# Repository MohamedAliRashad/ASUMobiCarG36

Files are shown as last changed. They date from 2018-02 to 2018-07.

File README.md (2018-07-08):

# ASUMobiCarG36
ASU project for a smart car

**Phase 1** video for the car click [Here](https://youtu.be/Kc8boilaBuo)

## Components

1- 2x motors like this [Here](https://store.fut-electronics.com/products/dc-geared-motor-with-metal-gear-8-8kg-250rpm-12v-1) ........................... [Done]

2- Ball Caster like [this](https://www.robotshop.com/en/pololu-ball-caster-3-8-in-metal-ball.html) ........................... [Done]

3- Bluetooth Module from [Here](https://store.fut-electronics.com/products/serial-bluetooth-module-master-slave) ........................... [Done]

4- Atmega chip (atmega328p was suggested) from [Here](https://store.fut-electronics.com/products/atmega328-microcontroller-with-bootloader-for-uno) ........................... [Done]

5- line follower sensor ........................... [Done]

## Assembling

**The Finished Car will look like this**
we have made a whole new Design for the Line Follower Competition and it looked like this.
The designs and edits are in the Designing Folder

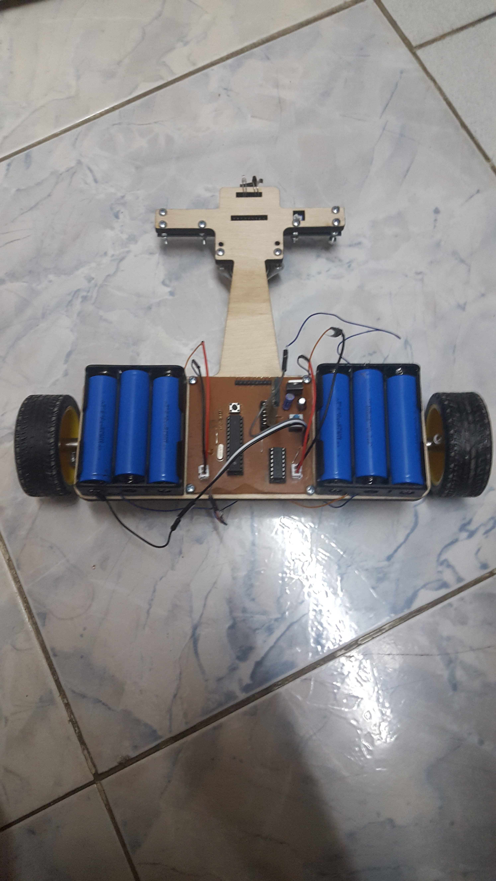
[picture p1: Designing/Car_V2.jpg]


## Programming
we have managed to program the car not only to be controlled by Bluetooth but with obstacle avoidance using IR sensor

## Line Following (Phase 2)
The Car Finished the proposed track as intended but with low speed which we are trying to improve right now.

**Phase 2** video for the Car **line following Mode** Click [Here](https://www.youtube.com/watch?v=1ZHcCvf_tag&feature=youtu.be)

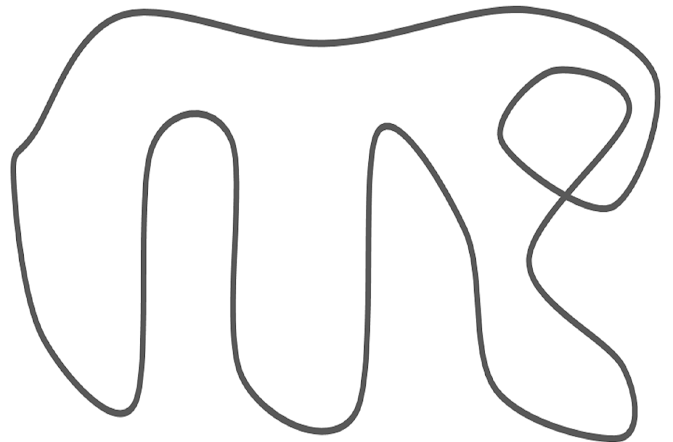
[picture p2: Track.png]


## Accurate Movement (Phase 3)

We managed to redesign the car for Accurate Movement and not to lose any important features we previously had.

**Phase 3** video for the car Click [Here](https://youtu.be/vXAHt9X1ldg)
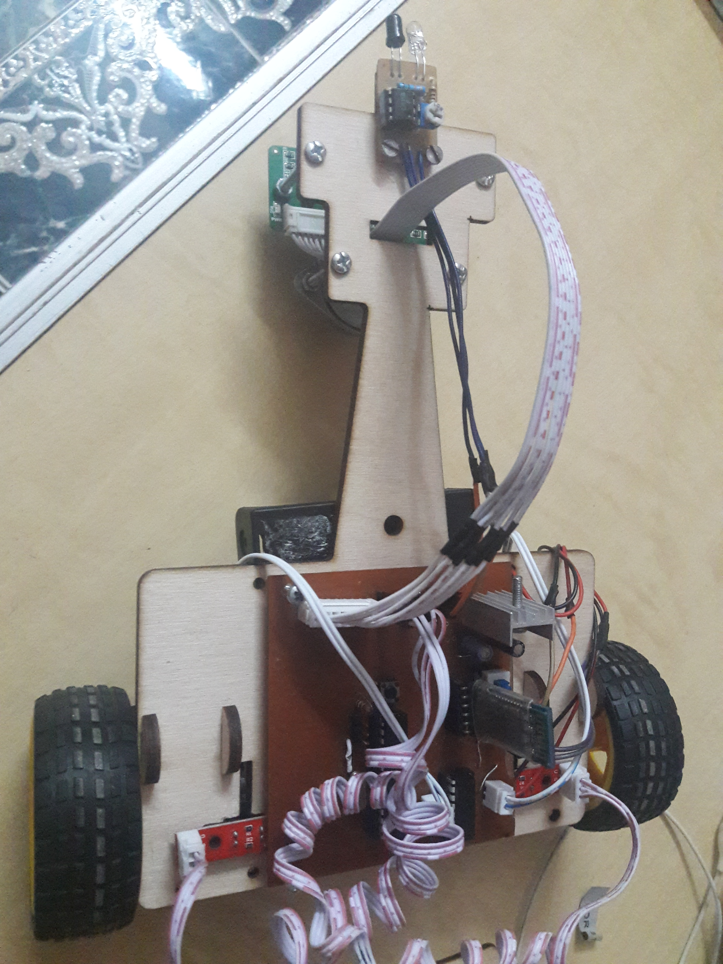
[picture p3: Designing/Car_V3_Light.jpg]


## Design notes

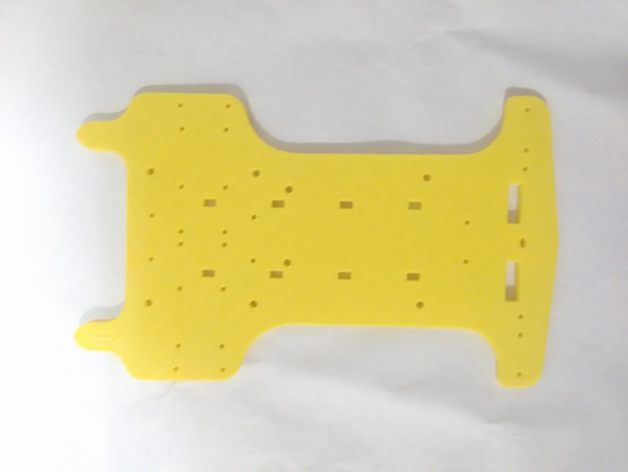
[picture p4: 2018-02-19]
Designing/Usain/images/0fe4a5ff5cf32486fa10856eb8f82ae0_preview_featured.jpg

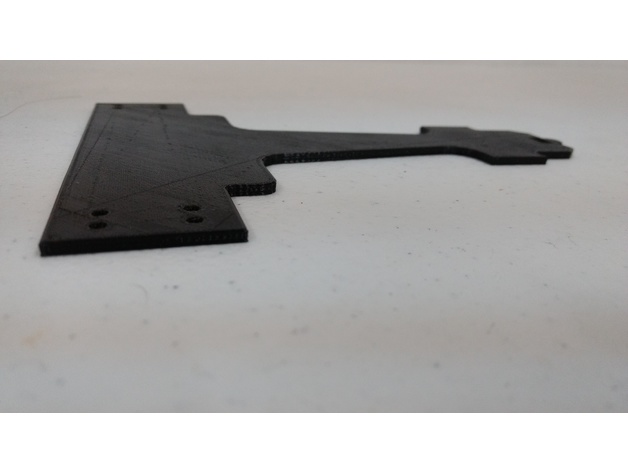
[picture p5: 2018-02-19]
Designing/Target/images/a4c6c6e0c1ed7add883d5088abed4bb4_preview_featured.jpg

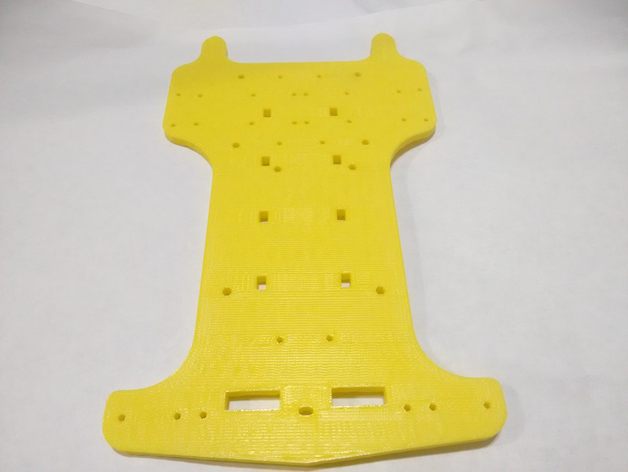
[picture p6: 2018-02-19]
Designing/Usain/images/7745294e8512e141715a2a82b8f7527b_preview_featured.jpg

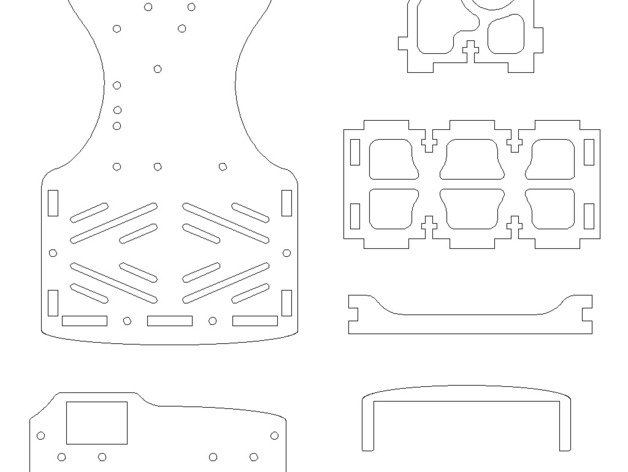
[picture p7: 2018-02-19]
Designing/Chariot/images/609b507f4311383388c29d5d0938cc0f_preview_featured.jpg

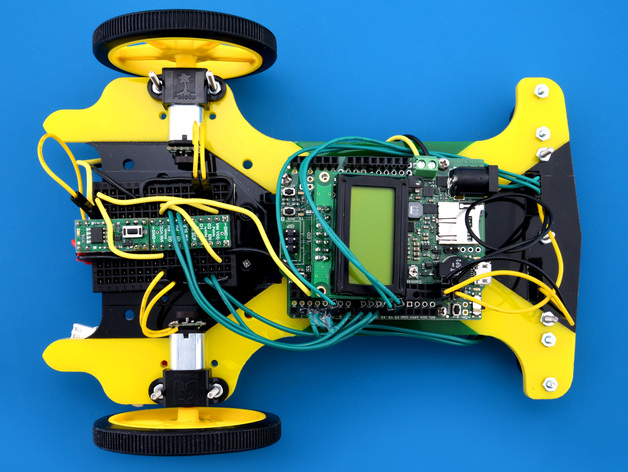
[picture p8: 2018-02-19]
Designing/Usain/images/top_preview_featured.jpg

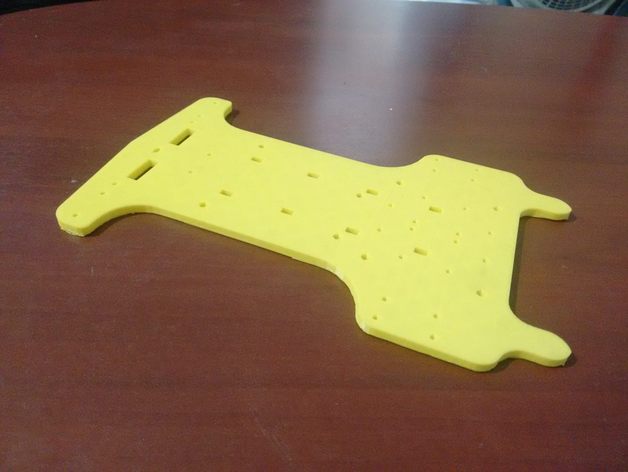
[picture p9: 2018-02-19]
Designing/Usain/images/d5540c52f5ededbf4ffe35892c21d28c_preview_featured.jpg

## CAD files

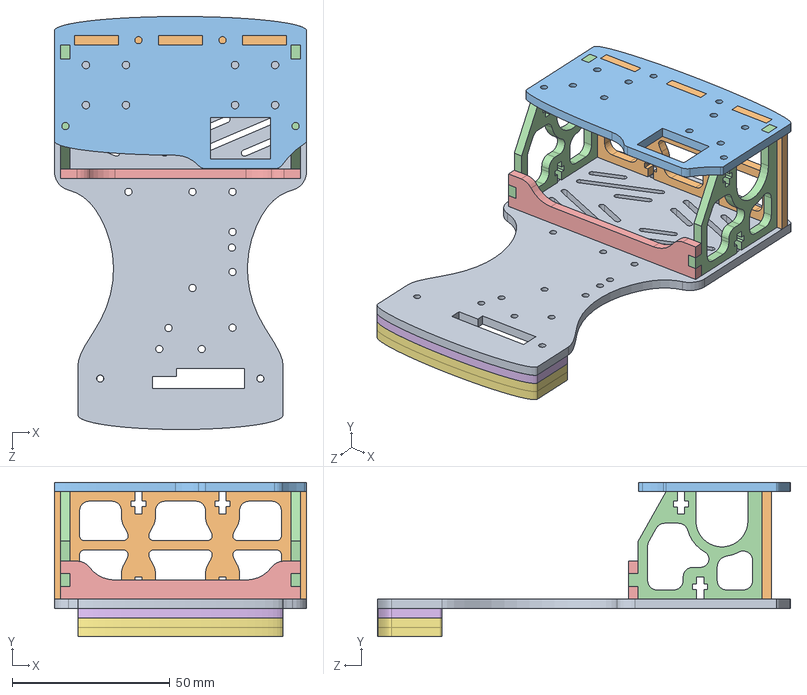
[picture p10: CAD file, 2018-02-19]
Designing/Chariot/files/bare-chassis.SLDASM
80.0 x 49.0 x 131.0 mm
chariot-base
chariot-back-wall
chariot-top
chariot-side-walls x 2
chariot-front-wall
chariot-led-shroud
chariot-led-shroud2 x 2

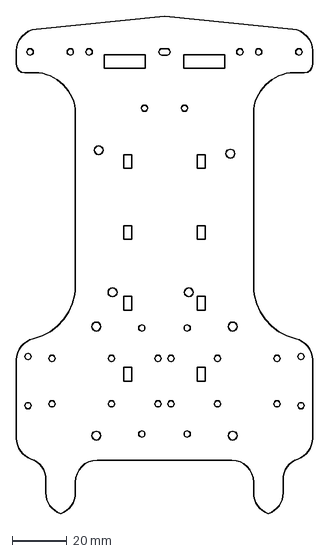
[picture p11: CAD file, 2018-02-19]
Designing/Usain/files/usain_volt_clear_full_body_piece.DXF
108.5 x 182.2 mm

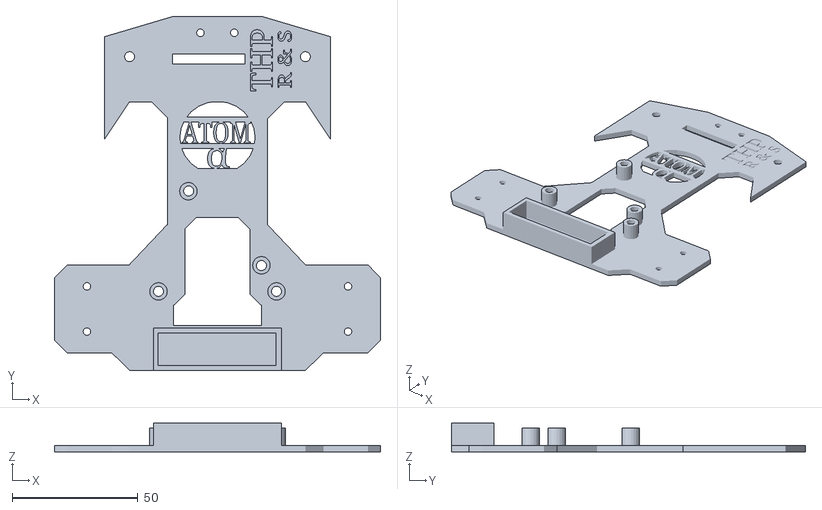
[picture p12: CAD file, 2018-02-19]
Designing/Atom/files/Atom_Alpha.stl
130.0 x 141.0 x 11.5

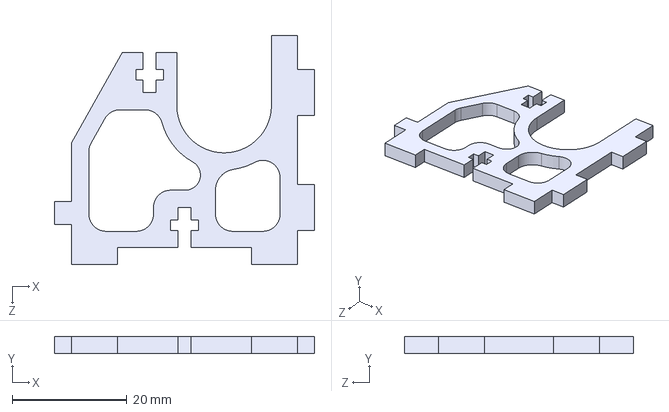
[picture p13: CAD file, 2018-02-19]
Designing/Chariot/files/chariot-side-walls.STEP
45.3 x 3.00 x 40.0 mm

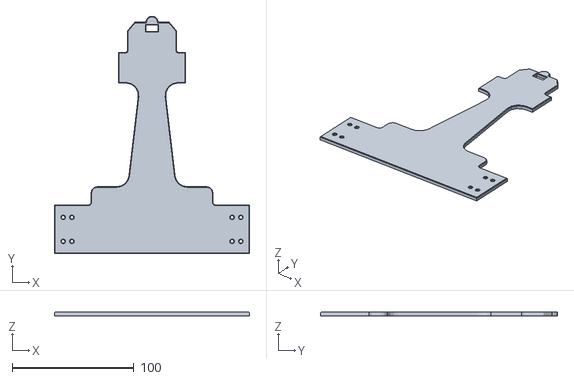
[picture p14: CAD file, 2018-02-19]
Designing/Target/files/chasis.stl
160.0 x 194.8 x 3.00

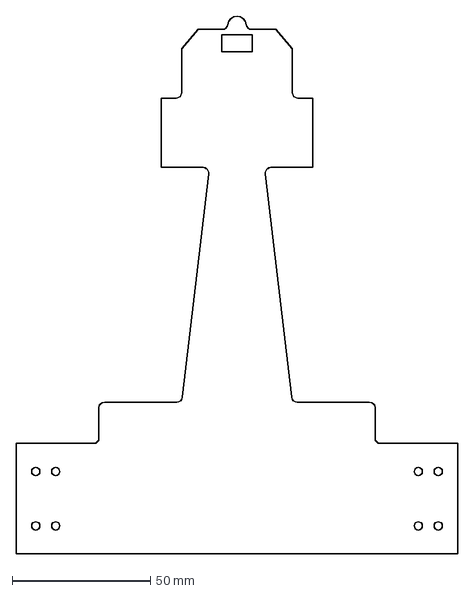
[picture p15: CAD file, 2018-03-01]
Designing/Target/Part1.DXF
160.0 x 194.8 mm

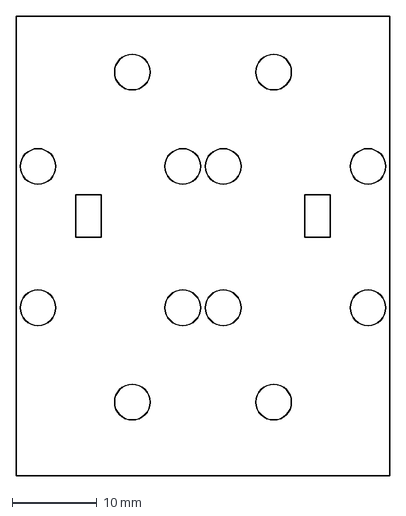
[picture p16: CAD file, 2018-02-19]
Designing/Usain/files/usain_volt_black_piece_under_breadboard.DXF
44.0 x 54.1 mm

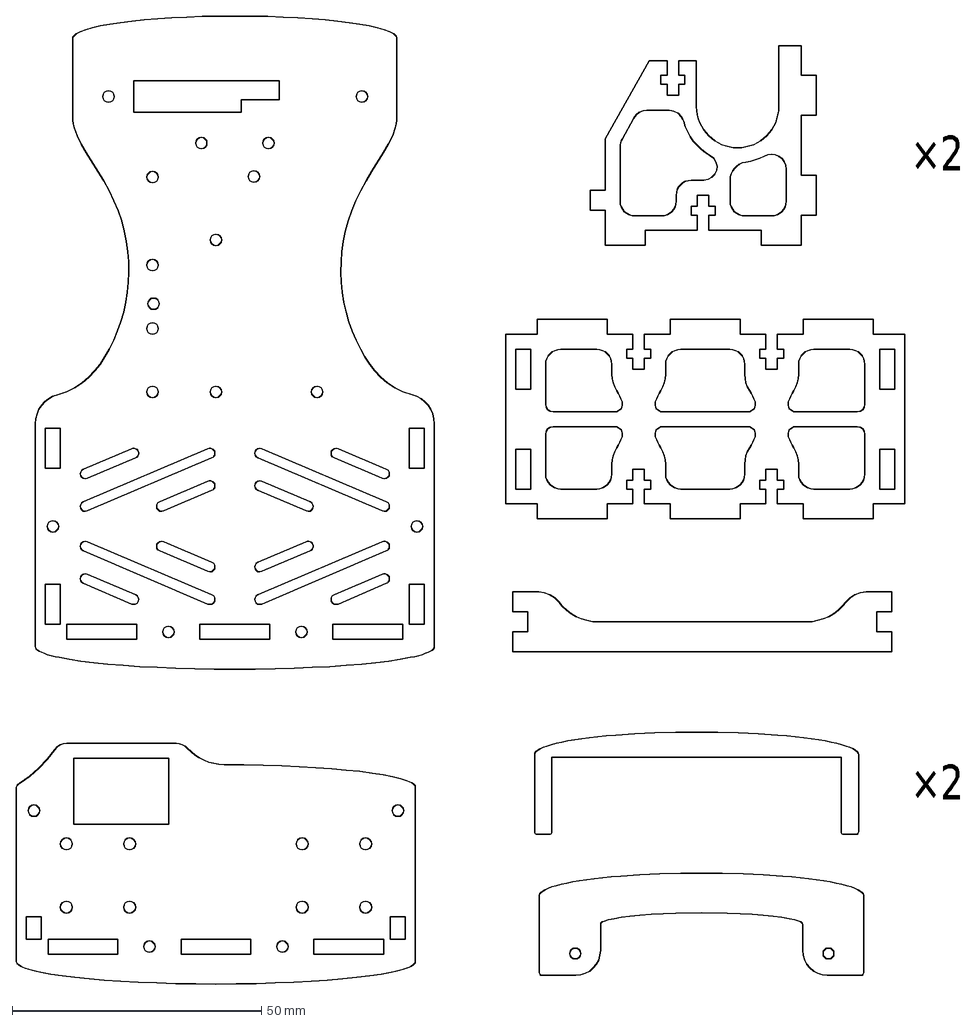
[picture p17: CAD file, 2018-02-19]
Designing/Chariot/files/the-chariot.DXF
×2

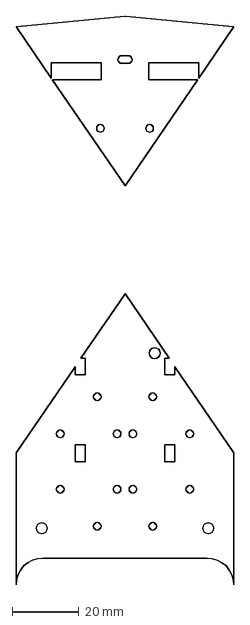
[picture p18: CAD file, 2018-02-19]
Designing/Usain/files/usain_volt_black_other_pieces.DXF
65.3 x 170.7 mm

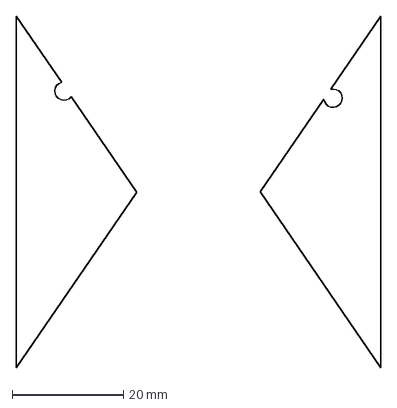
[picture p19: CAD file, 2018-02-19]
Designing/Usain/files/usain_volt_green_pieces.DXF
65.3 x 63.0 mm

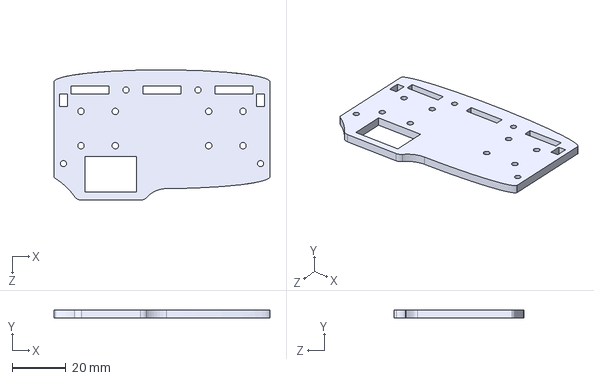
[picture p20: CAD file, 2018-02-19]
Designing/Chariot/files/chariot-top.STEP
80.0 x 3.00 x 48.3 mm

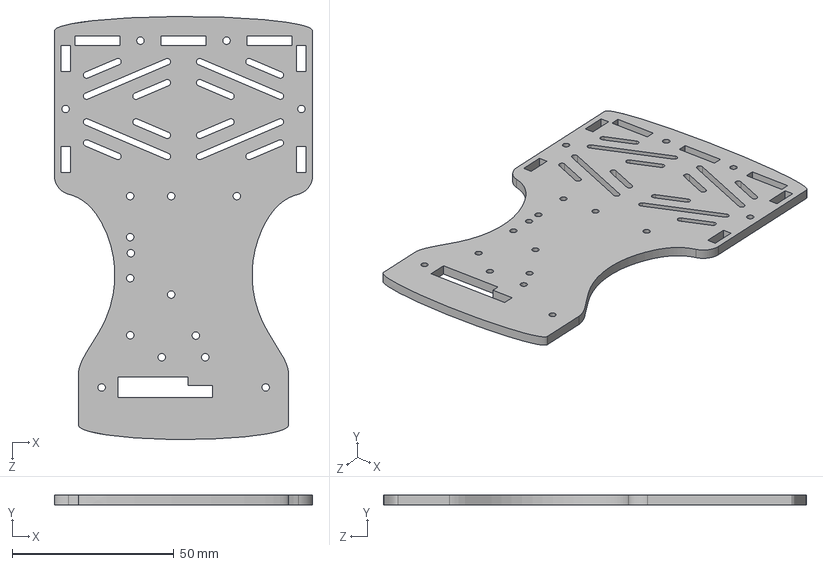
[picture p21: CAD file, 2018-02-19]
Designing/Chariot/files/chariot-base.STEP
80.0 x 3.00 x 131.0 mm

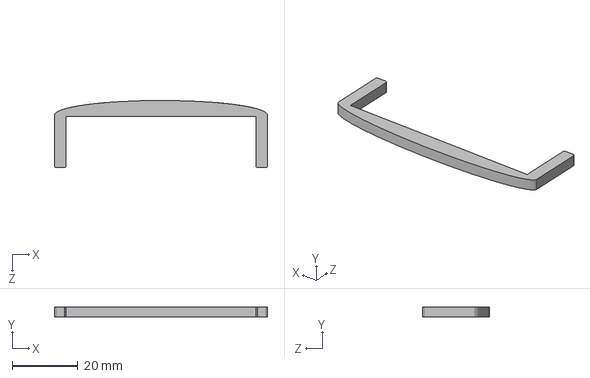
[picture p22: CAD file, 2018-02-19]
Designing/Chariot/files/chariot-led-shroud2.STEP
65.0 x 3.00 x 20.5 mm

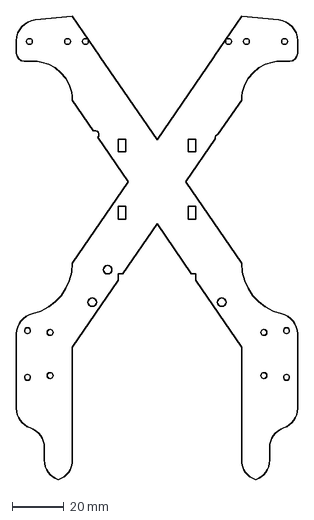
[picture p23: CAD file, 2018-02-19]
Designing/Usain/files/usain_volt_yellow_piece.DXF
108.5 x 179.0 mm

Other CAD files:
Designing/Design v3.0.SLDPRT
Designing/Motor Holders V3.0.SLDPRT
Designing/Chariot/files/chariot-front-wall.STEP
Designing/Chariot/files/chariot-led-shroud.STEP
Designing/Chariot/files/chariot-back-wall.SLDPRT
Designing/Chariot/files/chariot-back-wall.STEP
Designing/Chariot/files/chariot-base.SLDPRT
Designing/Chariot/files/chariot-front-wall.SLDPRT
Designing/Chariot/files/chariot-led-shroud.SLDPRT
Designing/Chariot/files/chariot-led-shroud2.SLDPRT
Designing/Chariot/files/chariot-side-walls.SLDPRT
Designing/Chariot/files/chariot-top.SLDPRT
Designing/Design V2.0.SLDPRT
Designing/Design v3.0.DXF
Designing/Motor Holders V2.0.SLDPRT
Designing/Motor Holders V3.0.DXF
Designing/Usain/files/Usain_Bolt.stl

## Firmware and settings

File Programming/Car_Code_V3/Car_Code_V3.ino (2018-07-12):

//#include <PID_v1.h>
#include <SoftwareSerial.h>

SoftwareSerial Bluetooth(A2, A3); // RX, TX

#define radiusOfCar 8 // Half the width of the car
#define PI 3.1415926535897932384626433832795
#define circumference 18.849555  //in CM
#define ML_pinA 10
#define ML_pinB 9
#define MR_pinA 11
#define MR_pinB 5
#define SS1_LEFT_OUT  9
#define SS2_LEFT_IN   8
#define SS3_CENTER    7
#define SS4_RIGHT_IN  6
#define SS5_RIGHT_OUT A0 
#define Near A5
#define Cal 4
#define EncR 2
#define EncL 3
#define FeedBack A4

void allpinslow();
void Forward(int Speed);
void Backward(int Speed);
void Right(int Speed);
void Left(int Speed);
int GetData();
void Around(int SpeedL, int SpeedR);
void MoveFDist(int x);
void MoveBDist(int x);
void docountR();
void docountL();
void MoveAngle(int y);
void MoSquare(int side);
void MoInfinity(int Radius);
void MoRCircle(int Radius);
void MoLCircle(int Radius);
void MoSquare(int side);
void LeftSafe(int Speed);
void RightSafe(int Speed);

//double SetPoint = 0, Input = 0, Output = 0;
char Data = 'S'; // the data received
unsigned int counterR=0;
unsigned int counterL=0;
unsigned int MaxSpeed = 127;
//char weights[5] = {0,-50,0,50,0};
//PID CarPID(&Input, &Output, &SetPoint,3,0,0,DIRECT);

void setup()
{
  pinMode(ML_pinA, OUTPUT);
  pinMode(ML_pinB, OUTPUT);
  pinMode(MR_pinA, OUTPUT);
  pinMode(MR_pinB, OUTPUT);
  pinMode(SS1_LEFT_OUT, INPUT);
  pinMode(SS2_LEFT_IN, INPUT);
  pinMode(SS3_CENTER, INPUT);
  pinMode(SS4_RIGHT_IN, INPUT);
  pinMode(SS5_RIGHT_OUT, INPUT);
  pinMode(Near, INPUT);
  pinMode(Cal, OUTPUT);
  pinMode(FeedBack, INPUT);
  pinMode(EncR, INPUT_PULLUP);
  pinMode(EncL, INPUT_PULLUP);
  
  //Initialization of all pin to be LOW
  allpinslow();

  //Initialzation of the PI
//  CarPID.SetMode(AUTOMATIC);

  //Setting Limits For the PID
  //CarPID.SetOutputLimits(-20, 20);

  //Install Bluetooth
  pinMode(A1, OUTPUT);
  digitalWrite(A1, HIGH);
  Bluetooth.begin(9600);
  Serial.begin(9600);

    //Command('S');
}

void loop() {

   /*
   if(digitalRead(Near)){
      Backward(MaxSpeed);
      delay(100);
      allpinslow();
      return;
    }
  */

  if (Bluetooth.available()) //wait for data received
  { 
    Data=Bluetooth.read();
    if (Data)
        Command(Data);
  }

   
}

void Command(char Comm)
{
  switch(Comm)
  { 
  
    case 'M':
    while(1){
      if(Bluetooth.read() == 'm'){
        allpinslow();
        break;
      }

      if (digitalRead(SS2_LEFT_IN) == 0 && digitalRead(SS3_CENTER) == 1 && digitalRead(SS4_RIGHT_IN) == 0) {
            Forward(MaxSpeed);
      }

      else if (digitalRead(SS2_LEFT_IN) == 1  && digitalRead(SS4_RIGHT_IN) == 0) {
  
        while (!(digitalRead(SS3_CENTER) == 1)) {
            LeftSafe(round(MaxSpeed * 0.5));
       }
     }
      else if (digitalRead(SS2_LEFT_IN) == 0 && digitalRead(SS4_RIGHT_IN) == 1) {

        while (!(digitalRead(SS3_CENTER) == 1)) {
            RightSafe(round(MaxSpeed * 0.5));
          }

      }
     else if (digitalRead(SS1_LEFT_OUT) == 1 && digitalRead(SS5_RIGHT_OUT) == 0){
      
        while (!(digitalRead(SS3_CENTER) == 1)) {
            LeftSafe(MaxSpeed);
       }
    }
    else if (digitalRead(SS1_LEFT_OUT) == 0 && digitalRead(SS5_RIGHT_OUT) == 1){
      
        while (!(digitalRead(SS3_CENTER) == 1)) {
            RightSafe(MaxSpeed);
       }

     }
    else
    {

        Forward(MaxSpeed);

    } 
     
    }

    break;

    case 'u':
    
    Around(100, 200);
    delay(10000);
    allpinslow();
    break;

    case 'f':    //Forward Automatic

    MoveFDist(GetData());

    break;

    case 'b':    //Backward Automatic

    MoveBDist(GetData());

    break;

    case 'a':    //Angle Automatic

    MoveAngle(GetData());

    break;

    case 's':    //Change Speed

    MaxSpeed = GetData();

    break;

    case 'q':    //Move square

    MoSquare(GetData());

    break;

    case 'r':    //Move Circle To the right

    MoRCircle(GetData());

    break;

    case 'l':    //Move Circle To the left

    MoLCircle(GetData());

    break;

    case 'i':    //Move Infinity Shape

    MoInfinity(GetData());

    break;

    case 'F':    //Forward Manual
 
    Forward(MaxSpeed);
    //Serial.println("Forward!");

    break;

    case 'G':    //Backward Manual
  
    Backward(MaxSpeed);
    //Serial.println("Backward!");
    break;
    
    case 'R':    //Right Manual
    
    Right(MaxSpeed);
    //Serial.println("Right!");
    break; 
    
    case 'L':    //Left Manual
  
    Left(MaxSpeed);

    break;     
    
    case 'S':
    
    allpinslow();
    
    break; 
  }
}

void allpinslow()
{
  digitalWrite(ML_pinA, LOW);
  digitalWrite(ML_pinB, LOW);
  digitalWrite(MR_pinA, LOW);
  digitalWrite(MR_pinB, LOW);
}

void Forward(int Speed) {

  analogWrite(ML_pinA, Speed);
  digitalWrite(ML_pinB, LOW);

  analogWrite(MR_pinA, Speed);
  digitalWrite(MR_pinB, LOW);

}
void Backward(int Speed) {

  digitalWrite(ML_pinA, LOW);
  analogWrite(ML_pinB, Speed);

  digitalWrite(MR_pinA, LOW);
  analogWrite(MR_pinB, Speed);


}
void Left(int Speed) {

  digitalWrite(ML_pinA, LOW);
  analogWrite(ML_pinB, Speed);

  analogWrite(MR_pinA, Speed);
  digitalWrite(MR_pinB, LOW);

}
void Right(int Speed) {

  analogWrite(ML_pinA, Speed);
  digitalWrite(ML_pinB, LOW);

  digitalWrite(MR_pinA, LOW);
  analogWrite(MR_pinB, Speed);

}
void LeftSafe(int Speed) {

  digitalWrite(ML_pinA, LOW);
  analogWrite(ML_pinB, LOW);

  analogWrite(MR_pinA, Speed);
  digitalWrite(MR_pinB, LOW);

}
void RightSafe(int Speed) {

  analogWrite(ML_pinA, Speed);
  digitalWrite(ML_pinB, LOW);

  digitalWrite(MR_pinA, LOW);
  digitalWrite(MR_pinB, LOW);

}

void Around(int SpeedL, int SpeedR) {

  analogWrite(ML_pinA, SpeedL);
  digitalWrite(ML_pinB, LOW);
  
  analogWrite(MR_pinA, SpeedR);
  digitalWrite(MR_pinB, LOW);
  

}

int GetData(){

  int Output = 0;
  char InArray[10];                    // Data will be held here as
  char count = 0;                     // Counting charcters received
  char data = Bluetooth.read();      // Data recieved From Bluetooth

  while(data != 'e' ){ 
  
    // Storing data from Bluetooth in an array
    if(data >= '0' && data <='9'){
      InArray[count] = data;
      count++;
    }
    data = Bluetooth.read();
  }

  // Transforming Charcters to integers
  for (char i = 0; i < count; i++){
        Output = Output + (InArray[i] - '0') * pow(10,count - i - 1);
  }
  if (Output >= 99)
      Output++;

  return Output;
}

void MoveFDist(int x){

  int NoInter = round((x/circumference) * 12);          // Transforming 

  attachInterrupt(digitalPinToInterrupt(EncR), docountR, RISING);
  //attachInterrupt(digitalPinToInterrupt(EncL), docountL, RISING);
  //if counterR < counterL 

  while (counterR < NoInter){
    Forward(MaxSpeed);
  }

  detachInterrupt(EncR);
  //detachInterrupt(EncL);

  counterR = 0;
  counterL = 0;
  
  allpinslow();
}


void MoveBDist(int x){

  int NoInter = round((x/circumference) * 12);          // Transforming 

  attachInterrupt(digitalPinToInterrupt(EncR), docountR, RISING);
  //attachInterrupt(digitalPinToInterrupt(EncL), docountL, RISING);
  //if counterR < counterL 

  while (counterR < NoInter){
    Backward(MaxSpeed);
  }

  detachInterrupt(EncR);
  //detachInterrupt(EncL);

  counterR = 0;
  counterL = 0;
  
  allpinslow();
}

void docountR()  // counts from the speed sensor
{
  counterR++;  // increase +1 the counter value
} 

void docountL()  // counts from the speed sensor
{
  counterL++;  // increase +1 the counter value
} 

void MoveAngle(int y){
 
  int NoInter = round(((y * PI/180) * radiusOfCar /circumference) * 12);

  attachInterrupt(digitalPinToInterrupt(EncR), docountR, FALLING);
  attachInterrupt(digitalPinToInterrupt(EncL), docountL, FALLING);
  //if counterR < counterL 

  while ((counterL + counterR) / 2 < NoInter){
    Right(MaxSpeed);
    //delay(10)
  }

  detachInterrupt(EncR);
  detachInterrupt(EncL);
  
  counterR = 0;
  counterL = 0;

  delay(25);
  allpinslow();
}

void MoSquare(int side){

  MoveFDist(side);
  delay(25);
  MoveAngle(90);
  delay(25);
  MoveFDist(side);
  delay(25);
  MoveAngle(90);
  delay(25);
  MoveFDist(side);
  delay(25);
  MoveAngle(90);
  delay(25);
  MoveFDist(side);
  delay(25);
  MoveAngle(90);
  
}

void MoRCircle(int Radius){

  int NoInter = round((2 * PI * (8 + Radius) / circumference ) * 12);

  attachInterrupt(digitalPinToInterrupt(EncL), docountL, FALLING);
  attachInterrupt(digitalPinToInterrupt(EncR), docountR, FALLING);
  
      while ((counterR + counterL) / 2 < NoInter){
        //Around(MaxSpeed, round(MaxSpeed * (Radius / (16 + Radius))));
        Around(200, 100);
      }

      detachInterrupt(EncL);
      detachInterrupt(EncR);

      counterR = 0;
      counterL = 0;
  
      allpinslow();

}

void MoLCircle(int Radius){


  int NoInter = round((2 * PI * (8 + Radius) / circumference ) * 12);

  attachInterrupt(digitalPinToInterrupt(EncL), docountL, FALLING);
  attachInterrupt(digitalPinToInterrupt(EncR), docountR, FALLING);
  
      while ((counterR + counterL) / 2 < NoInter){
        //Around(MaxSpeed, round(MaxSpeed * (Radius / (16 + Radius))));
        Around(100, 200);
      }

      detachInterrupt(EncL);
      detachInterrupt(EncR);

      counterR = 0;
      counterL = 0;
  
      allpinslow();
}

void MoInfinity(int Radius){

  MoRCircle(Radius);
  allpinslow();
  delay(10);
  MoLCircle(Radius);

}

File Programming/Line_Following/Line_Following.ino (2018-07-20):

#define Pwm 127
#define ML_pinA 5
#define ML_pinB 9
#define MR_pinA 11
#define MR_pinB 10
#define SS1_LEFT_OUT  7
#define SS2_LEFT_IN   6
#define SS3_CENTER    4
#define SS4_RIGHT_IN  3
#define SS5_RIGHT_OUT 2 
#define Near A5
#define CLP 7


void allpinslow();
void Forward(int Speed);
void Backward(int Speed);
void Right(int Speed1, int Speed2);
void Left(int Speed1, int Speed2);
double PWMtoSpeed(int PWM);

unsigned long StartTime;
unsigned long CurrentTime;
unsigned long duration;
float distance;
float hypotenuse;
float RaidusOfCurvature;
float Ratio;
int Pwm2;
bool FLAG;

void setup()
{
  pinMode(ML_pinA, OUTPUT);
  pinMode(ML_pinB, OUTPUT);
  pinMode(MR_pinA, OUTPUT);
  pinMode(MR_pinB, OUTPUT);
  pinMode(SS1_LEFT_OUT, INPUT);
  pinMode(SS2_LEFT_IN, INPUT);
  pinMode(SS3_CENTER, INPUT);
  pinMode(SS4_RIGHT_IN, INPUT);
  pinMode(SS5_RIGHT_OUT, INPUT);
  pinMode(Near, INPUT);
  pinMode(CLP, INPUT);
  
  //Initialization of all pin to be LOW
  allpinslow();

}

void loop() {

    Forward(Pwm);

    if(digitalRead(SS3_CENTER) == 1){
        StartTime = millis(); // We start the timing
        
        while(1){
            if(digitalRead(SS4_RIGHT_IN) == 0){
                CurrentTime = millis();
                FLAG = 1;
                break;
            }
            if(digitalRead(SS2_LEFT_IN) == 0){
                CurrentTime = millis();
                FLAG = 0;
                break;
            }
            Forward(Pwm);
        }
        duration = CurrentTime - StartTime; // The Duration of the white distance
        distance = PWMtoSpeed(Pwm) * duration; // The distance until the sensors go black
        hypotenuse = sqrt(pow(distance, 2) + pow(10, 2)); // getting the hypotenuse of the triangle
        RaidusOfCurvature = hypotenuse/0.087266; // The Raidus of the curve = the length of the curve which i approxmated to be the hypotenuse / The angle of the curve which i approxmated to be 5 degrees
        Ratio = (105 + RaidusOfCurvature) / (105 - RaidusOfCurvature); // The ratio between the speed of the motors
        Pwm2 = Ratio * Pwm; // Getting The others motor speed
        
        if(FLAG == 1)
        while(digitalRead(SS3_CENTER) == 1)
            Right(Pwm2, Pwm);
        else
        while(digitalRead(SS3_CENTER) == 1)
            Left(Pwm2, Pwm);

    } 
}

void allpinslow()
{
  digitalWrite(ML_pinA,LOW);
  digitalWrite(ML_pinB,LOW);
  digitalWrite(MR_pinA,LOW);
  digitalWrite(MR_pinB,LOW);
}

void Forward(int Speed)
{

    analogWrite(ML_pinA,Speed);
    digitalWrite(ML_pinB,LOW);
    
    analogWrite(MR_pinA,Speed);
    digitalWrite(MR_pinB,LOW);    
    
}
void Backward(int Speed)
{
    
    digitalWrite(ML_pinA,LOW);
    analogWrite(ML_pinB,Speed);
    
    digitalWrite(MR_pinA,LOW);
    analogWrite(MR_pinB,Speed); 
    

}
void Left(int Speed1, int Speed2 )
{

    digitalWrite(ML_pinA,LOW);
    analogWrite(ML_pinB,Speed1);
    
    analogWrite(MR_pinA,Speed2);
    digitalWrite(MR_pinB,LOW); 
  
}
void Right(int Speed1, int Speed2)
{

    analogWrite(ML_pinA,Speed1);
    digitalWrite(ML_pinB,LOW);
    
    digitalWrite(MR_pinA,LOW);
    analogWrite(MR_pinB,Speed2); 
  
}
double PWMtoSpeed(int PWM)
{

    return (13.8 * PWM + 73.86) * 0.01; //Speed in millimeters/milliseconds
    //return(-6.72 * pow(PWM,2) + 17.76 * PWM + 75.76)
    //return(1.28 * pow(PWM,3) - 7.081 * pow(PWM, 2) + 15.48 * PWM + 76.41)
    //return(-6.949 * pow(PWM, 4) + 4.308 * pow(PWM,3) - 6.281 * pow(PWM, 2) + 9.904 * PWM + 74.71)
    //return(10.66 * pow(PWM, 5) -6.949 * pow(PWM, 4) - 20.24 * pow(PWM,3) - 6.281 * pow(PWM, 2) + 09.89 * PWM + 74.71)
    
}

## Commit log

2018-02-19 add potential designs
    [Atom_Alpha.stl, Usain_Bolt.stl, bare-chassis.SLDASM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]
2018-02-20 Add files via upload
    This document illustrates how we can choose the best battery.
2018-02-21 sheet 2 - Embedded System Development Fundamentals
    Question 1 schematic
2018-02-26 sheet 2 Embedded System Development Fundamentals
    question 2 schematic
2018-03-08 Car Assembly
2018-03-09 Adding a script to test the sensor
2018-03-22 New Design
    [New Design.SLDPRT]
2018-03-22 Motor Holders
    [Motor Holders.SLDPRT]
2018-03-23 another pcb design
2018-03-26 Rearranging Folder
    [Atom_Alpha.stl, Motor Holders.SLDPRT, New Design.SLDPRT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]
2018-04-06 Create Code_PID
    PID Algorithm to optimize motors speeds
2018-07-04 Deign Changes
    [Design V2.0.SLDPRT, Design v3.0.DXF, Design v3.0.SLDPRT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]
2018-07-04 Create Arduino codes
